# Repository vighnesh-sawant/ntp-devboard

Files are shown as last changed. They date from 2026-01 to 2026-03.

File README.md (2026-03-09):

# A devboard with a gps module and ethernet
This devboard will work as stratum 1 NTP server and has support for PTP also which I plan on supporting. Since this is my first hardware project I have picked simple(?) components  
It will take time from the gps module and serve it as a ptp/ntp server over the lan9250.

# Why
Mostly for fun but I WANT MY LAPTOP TO HAVE MORE ACCURATE TIME THAN MY FRIENDS.
I used to do this same thing with a phone but its accuracy was on the same level as ntp over the public internet  
Thats why I wanted my own STRATUM 1 Server at home, this is also a good project for learning a variety of different stuff ranging from pcb development to writing drivers to messing with ptp.

# How
Get this pcb printed, make sure to get a gps module with a PPS pin and connect the pins via breadboard / soldering   
to the gpio pins of the rp2040, then use my firmware and connect the ethernet cable to your pc.  
Make sure to change the gpio pins in the header to the ones you have connected.
Change your ntp server to point to the rp2040's ip and then done!  
You have your own stratum 1 ntp server  
More instrucions coming after I get my PCB printed!

# Schematic and stuff





# BOM TABLE

| JLCPCB BOM Tool - BOM Matching | | | | | | | | | | | | | | | | | |
| --- | --- | --- | --- | --- | --- | --- | --- | --- | --- | --- | --- | --- | --- | --- | --- | --- | --- |
| BOM name：rev4_bom-JLCPCB Assembly Order.xlsx | | | Download Time：2026-03-09 22:30:55 | | | | * Our matching results are updated in real-time, but stock and prices may change. 
If it's been over 24 hours, please re-match before placing your order. |                |                                                                                                                                                                                                             |                                                            |                                                                                                                         |                   |                                                                          |          |     |           |                 |
| PCB Assembled Qty：5                                                                                         |                   |                                  | Est. Total Price：36.7342                    |               |                    |                   |                                                                                                                                                           |                |                                                                                                                                                                                                             |                                                            |                                                                                                                         |                   |                                                                          |          |     |           |                 |
| Your BOM                                                                                                    |                   |                                  |                                             |               | Matched Parts      |                   |                                                                                                                                                           |                |                                                                                                                                                                                                             |                                                            |                                                                                                                         | Order Information |                                                                          |          |     |           |                 |
| Top Designator                                                                                              | Bottom Designator | Comment                          | Footprint                                   | JLCPCB Part # | Matches            | Part #            | Manufacturer                                                                                                                                              | Footprint      | Description                                                                                                                                                                                                 | Category                                                   | Warning                                                                                                                 | JLCPCB Part #     | Product link                                                             | Lib Type | Qty | Source    | Total Price ($) |
| C1,C10,C23,C24                                                                                              |                   | 1uF                              | 0402                                        |               | Select by System   | CL05A105KA5NQNC   | Samsung Electro-Mechanics                                                                                                                                 | 0402           | 1uF 25V X5R ±10% 0402 Multilayer Ceramic Capacitors MLCC - SMD/SMT ROHS                                                                                                                                     | Multilayer Ceramic Capacitors MLCC - SMD/SMT               |                                                                                                                         | C52923            | https://jlcpcb.com/partdetail/53938-CL05A105KA5NQNC/C52923               | Basic    | 8   | 8 JLCPCB  | 0.032           |
| C11,C12,C17,C2,C20,C21,C22,C25,C26,C27,C28,C29,C3,C30,C31,C32,C33,C34,C35,C36,C38,C39,C4,C40,C5,C6,C7,C8,C9 |                   | 0.1uF                            | 0402                                        |               | Unconfirmed        | CL05B104KO5NNNC   | Samsung Electro-Mechanics                                                                                                                                 | 0402           | 100nF 16V X7R ±10% 0402 Multilayer Ceramic Capacitors MLCC - SMD/SMT ROHS                                                                                                                                   | Multilayer Ceramic Capacitors MLCC - SMD/SMT               | 1.The comment (CL05B104KO5NNNC) of this part does not match the one (0.1uF) provided in your BOM. Please confirm;       | C1525             | https://jlcpcb.com/partdetail/1877-CL05B104KO5NNNC/C1525                 | Basic    | 58  | 58 JLCPCB | 0.0754          |
| C13,C14                                                                                                     |                   | 10uF                             | 0603                                        |               | Select by System   | CL10A106KP8NNNC   | Samsung Electro-Mechanics                                                                                                                                 | 0603           | 10V 10uF X5R ±10% 0603 Multilayer Ceramic Capacitors MLCC - SMD/SMT ROHS                                                                                                                                    | Multilayer Ceramic Capacitors MLCC - SMD/SMT               |                                                                                                                         | C19702            | https://jlcpcb.com/partdetail/20411-CL10A106KP8NNNC/C19702               | Basic    | 4   | 4 JLCPCB  | 0.026           |
| C15,C16                                                                                                     |                   | 33pF                             | 0402                                        |               | Select by System   | 0402CG330J500NT   | FH (Guangdong Fenghua Advanced Tech)                                                                                                                      | 0402           | 33pF 50V C0G ±5% 0402 Multilayer Ceramic Capacitors MLCC - SMD/SMT ROHS                                                                                                                                     | Multilayer Ceramic Capacitors MLCC - SMD/SMT               |                                                                                                                         | C1562             | https://jlcpcb.com/partdetail/1914-0402CG330J500NT/C1562                 | Basic    | 4   | 4 JLCPCB  | 0.0048          |
| C18,C19                                                                                                     |                   | 15pF                             | 0402                                        |               | Select by System   | 0402CG150J500NT   | FH (Guangdong Fenghua Advanced Tech)                                                                                                                      | 0402           | 15pF 50V C0G ±5% 0402 Multilayer Ceramic Capacitors MLCC - SMD/SMT ROHS                                                                                                                                     | Multilayer Ceramic Capacitors MLCC - SMD/SMT               |                                                                                                                         | C1548             | https://jlcpcb.com/partdetail/1900-0402CG150J500NT/C1548                 | Basic    | 4   | 4 JLCPCB  | 0.0048          |
| C37                                                                                                         |                   | 470pF                            | 0805                                        |               | Select by System   | 0805B471K500NT    | FH (Guangdong Fenghua Advanced Tech)                                                                                                                      | 0805           | 470pF 50V X7R ±10% 0805 Multilayer Ceramic Capacitors MLCC - SMD/SMT ROHS                                                                                                                                   | Multilayer Ceramic Capacitors MLCC - SMD/SMT               |                                                                                                                         | C1743             | https://jlcpcb.com/partdetail/2095-0805B471K500NT/C1743                  | Basic    | 2   | 2 JLCPCB  | 0.0104          |
| FB1,FB2,FB3,FB4                                                                                             |                   | FerriteBead                      | 0603                                        |               | Select by Customer | GZ1608D601TF      | Sunlord                                                                                                                                                   | 0603           | -55℃~+125℃ 1 200mA 450mΩ 600Ω@100MHz ±25% 0603 Ferrite Beads ROHS                                                                                                                                           | Ferrite Beads                                              |                                                                                                                         | C1002             | https://jlcpcb.com/partdetail/Sunlord-GZ1608D601TF/C1002                 | Basic    | 8   | 8 JLCPCB  | 0.1048          |
| J1                                                                                                          |                   | USB_C_Receptacle_USB2.0_14P      | USB_C_Receptacle_HRO_TYPE-C-31-M-12         |               | Select by Customer | TYPE-C-31-M-12    | Korean Hroparts Elec                                                                                                                                      | SMD            | -30℃~+80℃ 1 10,000 cycles 16P 20V 5A 7.35mm Female Surface Mount, Right Angle Type-C SMD USB Connectors ROHS                                                                                                | USB Connectors                                             |                                                                                                                         | C165948           | https://jlcpcb.com/partdetail/Korean_HropartsElec-TYPE_C_31_M12/C165948  | Extended | 2   | 2 JLCPCB  | 0.362           |
| R1,R2                                                                                                       |                   | 5.1K                             | 0402                                        |               | Unconfirmed        | 0402WGF5101TCE    | UNI-ROYAL(Uniroyal Elec)                                                                                                                                  | 0402           | -55℃~+155℃ 5.1kΩ 50V 62.5mW Thick Film Resistor ±1% ±100ppm/℃ 0402 Chip Resistor - Surface Mount ROHS                                                                                                       | Chip Resistor - Surface Mount                              | 1.The comment (0402WGF5101TCE) of this part does not match the one (5.1K) provided in your BOM. Please confirm;         | C25905            | https://jlcpcb.com/partdetail/26648-0402WGF5101TCE/C25905                | Basic    | 4   | 4 JLCPCB  | 0.0032          |
| R3,R4                                                                                                       |                   | 22                               | 0402                                        |               | Unconfirmed        | 0402WGF220JTCE    | UNI-ROYAL(Uniroyal Elec)                                                                                                                                  | 0402           | -55℃~+155℃ 22Ω 50V 62.5mW Thick Film Resistor ±1% ±100ppm/℃ 0402 Chip Resistor - Surface Mount ROHS                                                                                                         | Chip Resistor - Surface Mount                              | 1.The comment (0402WGF220JTCE) of this part does not match the one (22) provided in your BOM. Please confirm;           | C25092            | https://jlcpcb.com/partdetail/25835-0402WGF220JTCE/C25092                | Basic    | 4   | 4 JLCPCB  | 0.0032          |
| R5,R6,R8                                                                                                    |                   | 1K                               | 0402                                        |               | Unconfirmed        | 0402WGF1001TCE    | UNI-ROYAL(Uniroyal Elec)                                                                                                                                  | 0402           | -55℃~+155℃ 1kΩ 50V 62.5mW Thick Film Resistor ±1% ±100ppm/℃ 0402 Chip Resistor - Surface Mount ROHS                                                                                                         | Chip Resistor - Surface Mount                              | 1.The comment (0402WGF1001TCE) of this part does not match the one (1K) provided in your BOM. Please confirm;           | C11702            | https://jlcpcb.com/partdetail/12256-0402WGF1001TCE/C11702                | Basic    | 6   | 6 JLCPCB  | 0.0042          |
| R10,R11,R12,R13,R16,R7,R9                                                                                   |                   | 10K                              | 0402                                        |               | Unconfirmed        | 0402WGF1002TCE    | UNI-ROYAL(Uniroyal Elec)                                                                                                                                  | 0402           | -55℃~+155℃ 10kΩ 50V 62.5mW Thick Film Resistor ±1% ±100ppm/℃ 0402 Chip Resistor - Surface Mount ROHS                                                                                                        | Chip Resistor - Surface Mount                              | 1.The comment (0402WGF1002TCE) of this part does not match the one (10K) provided in your BOM. Please confirm;          | C25744            | https://jlcpcb.com/partdetail/26487-0402WGF1002TCE/C25744                | Basic    | 14  | 14 JLCPCB | 0.0112          |
| R15                                                                                                         |                   | 12K                              | 0402                                        |               | Unconfirmed        | 0402WGF1202TCE    | UNI-ROYAL(Uniroyal Elec)                                                                                                                                  | 0402           | -55℃~+155℃ 12kΩ 50V 62.5mW Thick Film Resistor ±1% ±100ppm/℃ 0402 Chip Resistor - Surface Mount ROHS                                                                                                        | Chip Resistor - Surface Mount                              | 1.The comment (0402WGF1202TCE) of this part does not match the one (12K) provided in your BOM. Please confirm;          | C25752            | https://jlcpcb.com/partdetail/26495-0402WGF1202TCE/C25752                | Basic    | 2   | 2 JLCPCB  | 0.0014          |
| SW1                                                                                                         |                   | SW_Push                          | SW_Push_SPST_NO_Alps_SKRK                   |               | Select by Customer | TS-1088-AR02016   | XUNPU                                                                                                                                                     | SMD,4x3mm      | -30℃~+80℃ 1.6N 100,000 cycles 12V 2mm 3mm 4mm 50mA Black Round Button SMD(SMT) Tab SPST Surface Mount,Vertical Without Bracket SMD,4x3mm Tactile Switches ROHS                                              | Tactile Switches                                           |                                                                                                                         | C720477           | https://jlcpcb.com/partdetail/XUNPU-TS_1088AR02016/C720477               | Basic    | 2   | 2 JLCPCB  | 0.111           |
| U1                                                                                                          |                   | RP2040                           | QFN-56-1EP_7x7mm_P0.4mm_EP3.2x3.2mm         |               | Select by Customer | RP2040            | Raspberry Pi                                                                                                                                              | LQFN-56(7x7)   | 12bit 133MHz 30 LQFN-56(7x7) Microcontrollers (MCU/MPU/SOC) ROHS                                                                                                                                            | Microcontrollers (MCU/MPU/SOC)                             |                                                                                                                         | C2040             | https://jlcpcb.com/partdetail/RaspberryPi-RP2040/C2040                   | Extended | 2   | 2 JLCPCB  | 1.9298          |
| U2                                                                                                          |                   | MCP1700x-330xxTT                 | SOT-23                                      |               | Select by Customer | MCP1700T-3302E/TT | Microchip Tech                                                                                                                                            | SOT-23         | -40℃~+125℃@(Tj) 1 1.6uA 178mV@(250mA) 250mA 3.3V 44dB@(100Hz) 6V Fixed Over Temperature Protection、Short Circuit Protection Positive SOT-23 Voltage Regulators - Linear, Low Drop Out (LDO) Regulators ROHS | Voltage Regulators - Linear, Low Drop Out (LDO) Regulators |                                                                                                                         | C39051            | https://jlcpcb.com/partdetail/MicrochipTech-MCP1700T_3302ETT/C39051      | Extended | 5   | 5 JLCPCB  | 2.193           |
| U3                                                                                                          |                   | LAN9250/ML                       | QFN64_ML_MCH                                |               | Select by System   | LAN9250/ML        | Microchip Tech                                                                                                                                            | QFN-64-EP(9x9) | QFN-64-EP(9x9) Ethernet Controllers ROHS                                                                                                                                                                    | Ethernet Controllers                                       |                                                                                                                         | C633497           | https://jlcpcb.com/partdetail/MicrochipTech-LAN9250ML/C633497            | Extended | 2   | 2 JLCPCB  | 28.7744         |
| U4                                                                                                          |                   | W25Q16JVUXIQTR                   | Winbond_USON-8-1EP_3x2mm_P0.5mm_EP0.2x1.6mm |               | Select by Customer | W25Q16JVUXIQ      | Winbond Elec                                                                                                                                              | USON-8-EP(2x3) | -40℃~+85℃ 100,000 cycles 10uA 133MHz 16Mbit 2.7V~3.6V 20 Years 3ms SPI USON-8-EP(2x3) NOR FLASH ROHS                                                                                                        | NOR FLASH                                                  | 1.The comment (W25Q16JVUXIQ) of this part does not match the one (W25Q16JVUXIQTR) provided in your BOM. Please confirm; | C2843335          | https://jlcpcb.com/partdetail/WinbondElec-W25Q16JVUXIQ/C2843335          | Extended | 2   | 2 JLCPCB  | 2.792           |
| Y1                                                                                                          |                   | 12MHz                            | Crystal_SMD_3225-4Pin_3.2x2.5mm             |               | Select by Customer | X322512MSB4SI     | YXC Crystal Oscillators                                                                                                                                   | SMD3225-4P     | -40℃~+85℃ 12MHz 20pF Crystal Oscillator ±10ppm ±20ppm SMD3225-4P Crystals ROHS                                                                                                                              | Crystals                                                   |                                                                                                                         | C9002             | https://jlcpcb.com/partdetail/YXC_CrystalOscillators-X322512MSB4SI/C9002 | Basic    | 2   | 2 JLCPCB  | 0.145           |
| Y2                                                                                                          |                   | 25MHz                            | Crystal_SMD_3225-4Pin_3.2x2.5mm             |               | Select by Customer | X322525MOB4SI     | YXC Crystal Oscillators                                                                                                                                   | SMD3225-4P     | -40℃~+85℃ 12pF 25MHz Crystal Oscillator ±10ppm ±20ppm SMD3225-4P Crystals ROHS                                                                                                                              | Crystals                                                   |                                                                                                                         | C9006             | https://jlcpcb.com/partdetail/YXC_CrystalOscillators-X322525MOB4SI/C9006 | Basic    | 2   | 2 JLCPCB  | 0.1456          |
| J2                                                                                                          |                   | Conn_01x07                       | PinHeader_1x07_P2.54mm_Vertical             |               | No matches         | No Part Selected  |                                                                                                                                                           |                |                                                                                                                                                                                                             |                                                            |                                                                                                                         |                   |                                                                          |          |     |           |                 |
| J4                                                                                                          |                   | Conn_01x04                       | PinHeader_1x04_P2.54mm_Vertical             |               | No matches         | No Part Selected  |                                                                                                                                                           |                |                                                                                                                                                                                                             |                                                            |                                                                                                                         |                   |                                                                          |          |     |           |                 |
| J5                                                                                                          |                   | Conn_01x02                       | PinHeader_1x02_P2.54mm_Vertical             |               | No matches         | No Part Selected  |                                                                                                                                                           |                |                                                                                                                                                                                                             |                                                            |                                                                                                                         |                   |                                                                          |          |     |           |                 |
| J6                                                                                                          |                   | RJ45_Hanrun_HR911105A_Horizontal | RJ45_Hanrun_HR911105A_Horizontal            |               | No matches         | No Part Selected  |                                                                                                                                                           |                |                                                                                                                                                                                                             |                                                            |                                                                                                                         |                   |                                                                          |          |     |           |                 |
| Index | LCSC#    | MPN                   | Manufacturer                  | Package               | Customer # | Description                                                           | RoHS | Quantity | MOQ | Multiple | Unit Price($) | Extended Price($) | Product Link                                      |
| ------ | -------- | --------------------- | ----------------------------- | --------------------- | ---------- | --------------------------------------------------------------------- | ---- | -------- | --- | -------- | ------------- | ----------------- | ------------------------------------------------- |
| 1      | C12074   | HR911105A             | HANRUN(Zhongshan HanRun Elec) | Through Hole          |            | Jack Modular Connector RJ45 Through Hole                              | yes  | 2        | 1   | 1        | 1.4814        | 2.96              | https://www.lcsc.com/product-detail/C12074.html   |
| 2      | C2337    | 2.54-1*40P            | BOOMELE(Boom Precision Elec)  | Through Hole,P=2.54mm |            | Pin Header 40 Position 2.54mm Pitch Single Row Through Hole -25℃~+85℃ | yes  | 5        | 5   | 5        | 0.1372        | 0.69              | https://www.lcsc.com/product-detail/C2337.html    |
| 3      | C5139763 | HS13L01WZ01           | HS                            | -                     |            | 1.3 128x64 sh1106 SPI LCD, OLED, Graphic RoHS                         | yes  | 2        | 1   | 1        | 4.6311        | 9.26              | https://www.lcsc.com/product-detail/C5139763.html |
| 4      | C9753    | DS18B20+              | MAXIM                         | TO-92                 |            | -55℃~+125℃ Single-bus 3V~5.5V TO-92 Analog and Digital Output RoHS    | yes  | 1        | 1   | 1        | 1.1630        | 1.16              | https://www.lcsc.com/product-detail/C9753.html    |
| 5      | C784382  | BWGNSCNX18-18B1Y2L120 | BAT WIRELESS                  | -                     |            | RF ANTENNA Ceramic                                                    | yes  | 1        | 1   | 1        | 1.6729        | 1.67              | https://www.lcsc.com/product-detail/C784382.html  |

A Gps module with a PPS pin https://roboticsdna.in/product/gps-neo-6m-satellite-positioning-module-development-board-for-arduino-stm32-51/  
Jumper wire https://roboticsdna.in/product/65pcs-flexible-breadboard-jumper-wires/  
Bread Board https://roboticsdna.in/product/syb-170-black-mini-solderless-breadboard/

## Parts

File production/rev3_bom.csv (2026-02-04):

Designator | Footprint | Quantity | Value | LCSC Part #
C1, C10, C23, C24 | 0402 | 4 | 1uF
C11, C12, C17, C2, C20, C21, C22, C25, C26, C27, C28, C29, C3, C30, C31, C32, C33, C34, C35, C36, C38, C39, C4, C40, C5, C6, C7, C8, C9 | 0402 | 29 | 0.1uF
C13, C14 | 0603 | 2 | 10uF
C15, C16 | 0402 | 2 | 33pF
C18, C19 | 0402 | 2 | 15pF
C37 | 0805 | 1 | 470pF
FB1, FB2, FB3, FB4 | 0603 | 4 | FerriteBead
J1 | USB_C_Receptacle_HRO_TYPE-C-31-M-12 | 1 | USB_C_Receptacle_USB2.0_14P
J2 | PinHeader_1x07_P2.54mm_Vertical | 1 | Conn_01x07
J3 | PinHeader_1x20_P2.54mm_Vertical | 1 | Conn_01x20
J4 | PinHeader_1x04_P2.54mm_Vertical | 1 | Conn_01x04
J5 | PinHeader_1x02_P2.54mm_Vertical | 1 | Conn_01x02
J6 | RJ45_Hanrun_HR911105A_Horizontal | 1 | RJ45_Hanrun_HR911105A_Horizontal
R1, R2 | 0402 | 2 | 5.1K
R10, R11, R12, R13, R16, R7, R9 | 0402 | 7 | 10K
R15 | 0402 | 1 | 12K
R3, R4 | 0402 | 2 | 22
R5, R6, R8 | 0402 | 3 | 1K
SW1 | SW_Push_SPST_NO_Alps_SKRK | 1 | SW_Push
U1 | QFN-56-1EP_7x7mm_P0.4mm_EP3.2x3.2mm | 1 | RP2040
U2 | SOT-23 | 1 | MCP1700x-330xxTT
U3 | QFN64_ML_MCH | 1 | LAN9250/ML
U4 | Winbond_USON-8-1EP_3x2mm_P0.5mm_EP0.2x1.6mm | 1 | W25Q16JVUXIQ TR
Y1 | Crystal_SMD_3225-4Pin_3.2x2.5mm | 1 | 12 MHz
Y2 | Crystal_SMD_3225-4Pin_3.2x2.5mm | 1 | 25 MHz

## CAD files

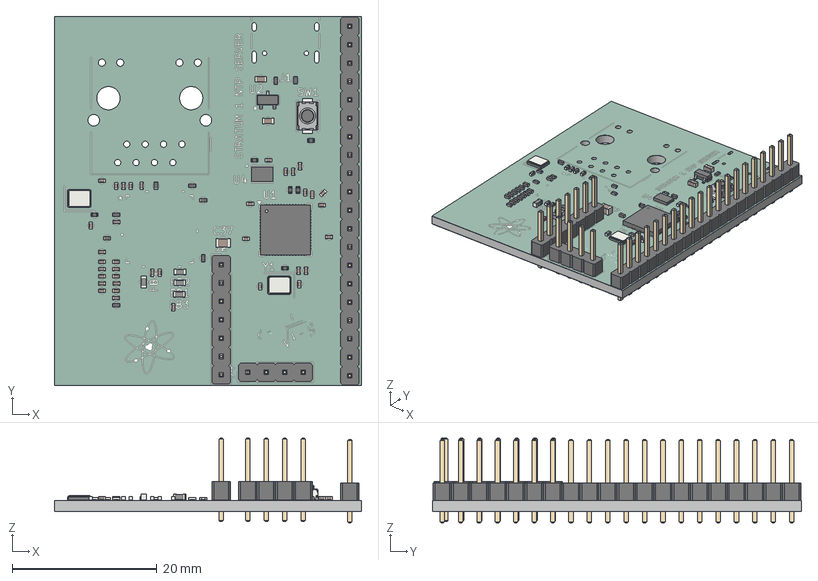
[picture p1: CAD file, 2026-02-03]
ntp-devboard.step
42.4 x 51.0 x 11.7 mm
C_0402_1005Metric x 37
R_0402_1005Metric x 15
C_0603_1608Metric x 2
Crystal_SMD_3225-4Pin_3.2x2.5mm x 2
L_0603_1608Metric x 4
PinHeader_1x04_P2.54mm_Vertical
C_0805_2012Metric
SW_Push_SPST_NO_Alps_SKRK
PinHeader_1x07_P2.54mm_Vertical
QFN-56-1EP_7x7mm_P0.4mm_EP3.2x3.2mm
SOT-23
Winbond_USON-8-1EP_3x2mm_P0.5mm_EP0.2x1.6mm
PinHeader_1x20_P2.54mm_Vertical
ntp-devboard_silkscreen x 2
ntp-devboard_soldermask x 2
ntp-devboard_PCB

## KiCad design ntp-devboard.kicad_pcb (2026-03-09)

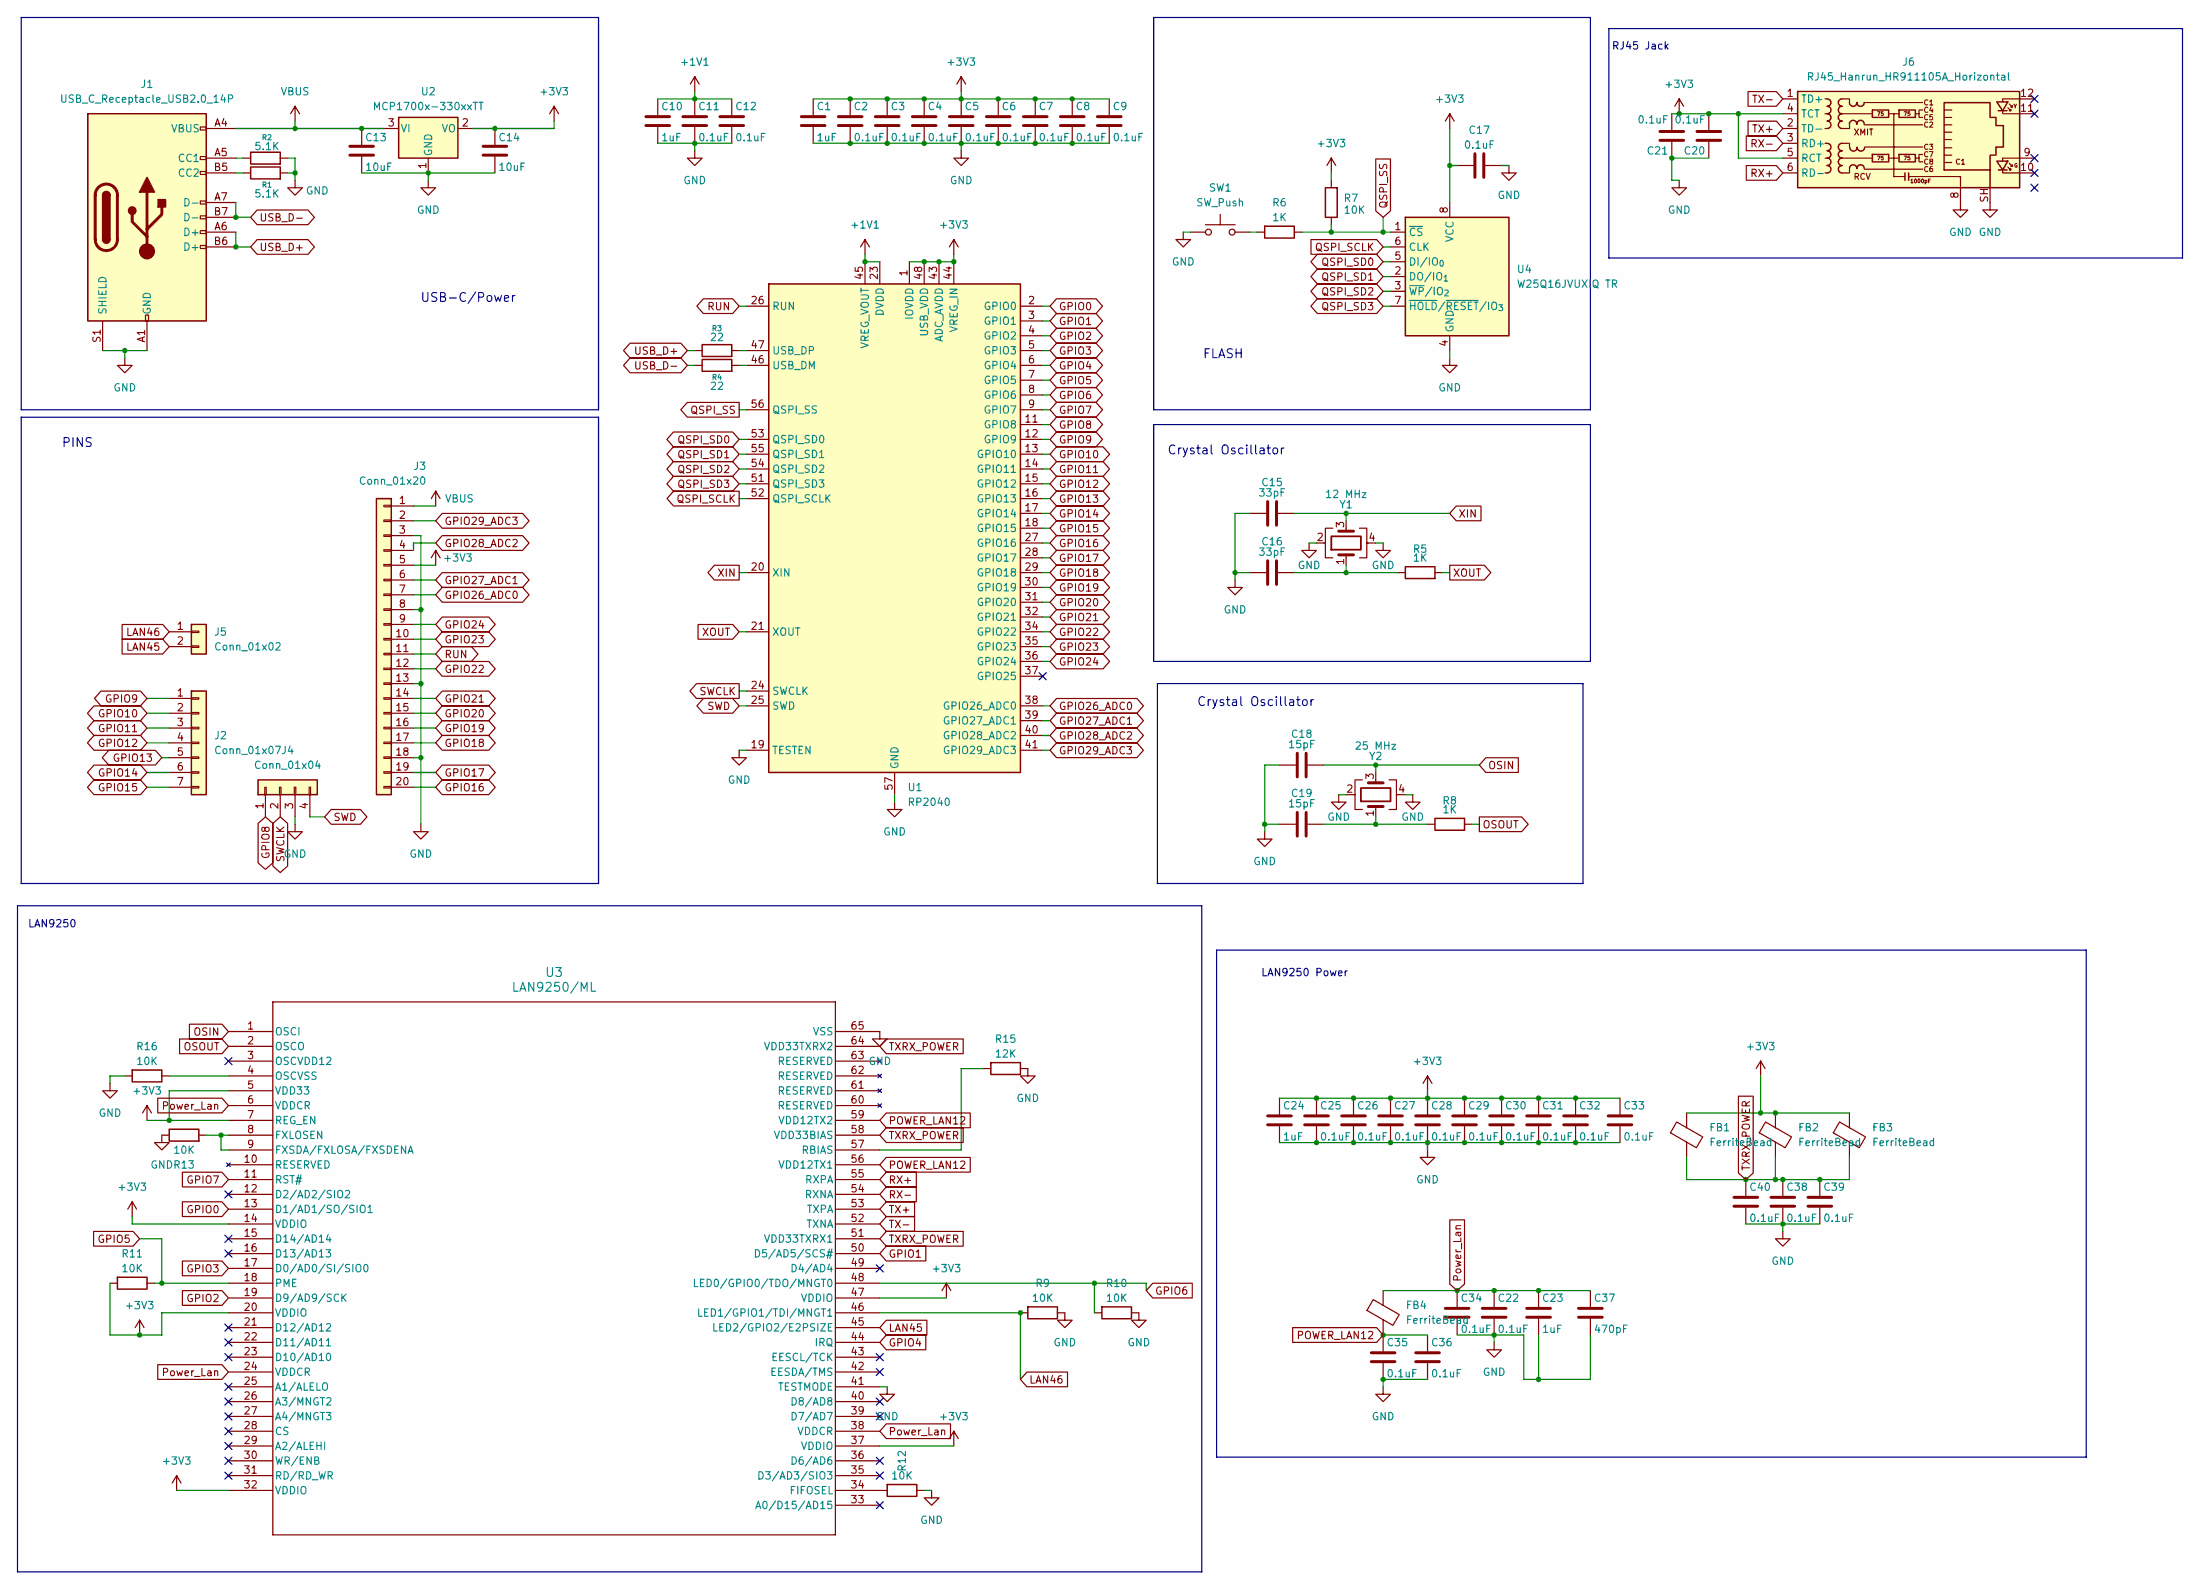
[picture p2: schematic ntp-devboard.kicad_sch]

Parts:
C1, C10, C23, C24: 1uF; C_0402_1005Metric
C2, C3, C4, C5, C6, C7, C8, C9, C11, C12, C17, C20, C21, C22, C25, C26, C27, C28, C29, C30, C31, C32, C33, C34, C35, C36, C38, C39, C40: 0.1uF; C_0402_1005Metric
C13, C14: 10uF; C_0603_1608Metric
C15, C16: 33pF; C_0402_1005Metric
C18, C19: 15pF; C_0402_1005Metric
C37: 470pF; C_0805_2012Metric
FB1, FB2, FB3, FB4: FerriteBead; L_0603_1608Metric
J1: USB_C_Receptacle_USB2.0_14P; USB_C_Receptacle_HRO_TYPE-C-31-M-12
J2: Conn_01x07; PinHeader_1x07_P2.54mm_Vertical
J3: Conn_01x20; PinHeader_1x20_P2.54mm_Vertical
J4: Conn_01x04; PinHeader_1x04_P2.54mm_Vertical
J5: Conn_01x02; PinHeader_1x02_P2.54mm_Vertical
J6: RJ45_Hanrun_HR911105A_Horizontal
R1, R2: 5.1K; R_0402_1005Metric
R3, R4: 22; R_0402_1005Metric
R5, R6, R8: 1K; R_0402_1005Metric
R7, R9, R10, R11, R12, R13, R16: 10K; R_0402_1005Metric
R15: 12K; R_0402_1005Metric
SW1: SW_Push; SW_Push_SPST_NO_Alps_SKRK
U1: RP2040; QFN-56-1EP_7x7mm_P0.4mm_EP3.2x3.2mm
U2: MCP1700x-330xxTT; SOT-23
U3: LAN9250/ML; QFN64_ML_MCH
U4: W25Q16JVUXIQ TR; Winbond_USON-8-1EP_3x2mm_P0.5mm_EP0.2x1.6mm
Y1: 12 MHz; Crystal_SMD_3225-4Pin_3.2x2.5mm
Y2: 25 MHz; Crystal_SMD_3225-4Pin_3.2x2.5mm

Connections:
+1V1: C10.1, C11.1, C12.1, U1.23 (DVDD), U1.45 (VREG_VOUT), U1.50 (DVDD)
+3V3: C1.1, C2.1, C3.1, C4.1, C5.1, C6.1, C7.1, C8.1, C9.1, C14.1, C17.1, C20.2, C21.2, C24.1, C25.1, C26.1, C27.1, C28.1, C29.1, C30.1, C31.1, C32.1, C33.1, FB1.1, FB2.1, FB3.1, J3.5, J6.4 (TCT), J6.5 (RCT), R7.2, R11.2, U1.1 (IOVDD), U1.10 (IOVDD), U1.22 (IOVDD), U1.33 (IOVDD), U1.42 (IOVDD), U1.43 (ADC_AVDD), U1.44 (VREG_IN), U1.48 (USB_VDD), U1.49 (IOVDD), U2.2 (VO), U3.5 (VDD33), U3.7 (REG_EN), U3.14 (VDDIO), U3.20 (VDDIO), U3.32 (VDDIO), U3.37 (VDDIO), U3.47 (VDDIO), U4.8 (VCC)
GND: C1.2, C2.2, C3.2, C4.2, C5.2, C6.2, C7.2, C8.2, C9.2, C10.2, C11.2, C12.2, C13.2, C14.2, C15.1, C16.1, C17.2, C18.1, C19.1, C20.1, C21.1, C22.2, C23.2, C24.2, C25.2, C26.2, C27.2, C28.2, C29.2, C30.2, C31.2, C32.2, C33.2, C34.2, C35.2, C36.2, C37.2, C38.2, C39.2, C40.2, J1.A1 (GND), J1.A12 (GND), J1.B1 (GND), J1.B12 (GND), J1.S1 (SHIELD), J3.3, J3.8, J3.13, J3.18, J4.3, J6.8, J6.SH, R1.2, R2.2, R9.1, R10.1, R12.1, R13.1, R15.1, R16.2, SW1.1, U1.19 (TESTEN), U1.57 (GND), U2.1 (GND), U3.41 (TESTMODE), U3.65 (VSS), U4.4 (GND), Y1.2, Y1.4, Y2.2, Y2.4
GPIO0: U1.2 (GPIO0), U3.13 (D1/AD1/SO/SIO1)
GPIO1: U1.3 (GPIO1), U3.50 (D5/AD5/SCS#)
GPIO2: U1.4 (GPIO2), U3.19 (D9/AD9/SCK)
GPIO3: U1.5 (GPIO3), U3.17 (D0/AD0/SI/SIO0)
GPIO4: U1.6 (GPIO4), U3.44 (IRQ)
GPIO5: R11.1, U1.7 (GPIO5), U3.18 (PME)
GPIO6: R10.2, U1.8 (GPIO6), U3.48 (LED0/GPIO0/TDO/MNGT0)
GPIO7: U1.9 (GPIO7), U3.11 (RST#)
GPIO8: J4.1, U1.11 (GPIO8)
GPIO9: J2.1, U1.12 (GPIO9)
GPIO10: J2.2, U1.13 (GPIO10)
GPIO11: J2.3, U1.14 (GPIO11)
GPIO12: J2.4, U1.15 (GPIO12)
GPIO13: J2.5, U1.16 (GPIO13)
GPIO14: J2.6, U1.17 (GPIO14)
GPIO15: J2.7, U1.18 (GPIO15)
GPIO16: J3.20, U1.27 (GPIO16)
GPIO17: J3.19, U1.28 (GPIO17)
GPIO18: J3.17, U1.29 (GPIO18)
GPIO19: J3.16, U1.30 (GPIO19)
GPIO20: J3.15, U1.31 (GPIO20)
GPIO21: J3.14, U1.32 (GPIO21)
GPIO22: J3.12, U1.34 (GPIO22)
GPIO23: J3.10, U1.35 (GPIO23)
GPIO24: J3.9, U1.36 (GPIO24)
GPIO26_ADC0: J3.7, U1.38 (GPIO26_ADC0)
GPIO27_ADC1: J3.6, U1.39 (GPIO27_ADC1)
GPIO28_ADC2: J3.4, U1.40 (GPIO28_ADC2)
GPIO29_ADC3: J3.2, U1.41 (GPIO29_ADC3)
LAN45: J5.2, U3.45 (LED2/GPIO2/E2PSIZE)
LAN46: J5.1, R9.2, U3.46 (LED1/GPIO1/TDI/MNGT1)
unnamed: C16.2, R5.1, Y1.1
unnamed: C19.2, R8.1, Y2.1
unnamed: J1.A5 (CC1), R2.1
unnamed: J1.B5 (CC2), R1.1
unnamed: R6.2, SW1.2
unnamed: R4.2, U1.46 (USB_DM)
unnamed: R3.2, U1.47 (USB_DP)
unnamed: R12.2, U3.34 (FIFOSEL)
unnamed: R13.2, U3.8 (FXLOSEN), U3.9 (FXSDA/FXLOSA/FXSDENA)
unnamed: R16.1, U3.4 (OSCVSS)
unnamed: R15.2, U3.57 (RBIAS)
OSIN: C18.2, U3.1 (OSCI), Y2.3
OSOUT: R8.2, U3.2 (OSCO)
POWER_LAN12: C35.1, C36.1, FB4.2, U3.56 (VDD12TX1), U3.59 (VDD12TX2)
Power_Lan: C22.1, C23.1, C34.1, C37.1, FB4.1, U3.6 (VDDCR), U3.24 (VDDCR), U3.38 (VDDCR)
QSPI_SCLK: U1.52 (QSPI_SCLK), U4.6 (CLK)
QSPI_SD0: U1.53 (QSPI_SD0), U4.5 (DI/IO_{0})
QSPI_SD1: U1.55 (QSPI_SD1), U4.2 (DO/IO_{1})
QSPI_SD2: U1.54 (QSPI_SD2), U4.3 (~WP/IO_{2})
QSPI_SD3: U1.51 (QSPI_SD3), U4.7 (~HOLD/~RESET/IO_{3})
QSPI_SS: R6.1, R7.1, U1.56 (QSPI_SS), U4.1 (~CS)
RUN: J3.11, U1.26 (RUN)
RX+: J6.6 (RD-), U3.55 (RXPA)
RX-: J6.3 (RD+), U3.54 (RXNA)
SWCLK: J4.2, U1.24 (SWCLK)
SWD: J4.4, U1.25 (SWD)
TX+: J6.2 (TD-), U3.53 (TXPA)
TX-: J6.1 (TD+), U3.52 (TXNA)
TXRX_POWER: C38.1, C39.1, C40.1, FB1.2, FB2.2, FB3.2, U3.51 (VDD33TXRX1), U3.58 (VDD33BIAS), U3.64 (VDD33TXRX2)
USB_D+: J1.A6 (D+), J1.B6 (D+), R3.1
USB_D-: J1.A7 (D-), J1.B7 (D-), R4.1
VBUS: C13.1, J1.A4 (VBUS), J1.A9 (VBUS), J1.B4 (VBUS), J1.B9 (VBUS), J3.1, U2.3 (VI)
XIN: C15.2, U1.20 (XIN), Y1.3
XOUT: R5.2, U1.21 (XOUT)

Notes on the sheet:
FLASH
PINS
LAN9250 Power
RJ45 Jack
LAN9250
Crystal Oscillator
USB-C/Power

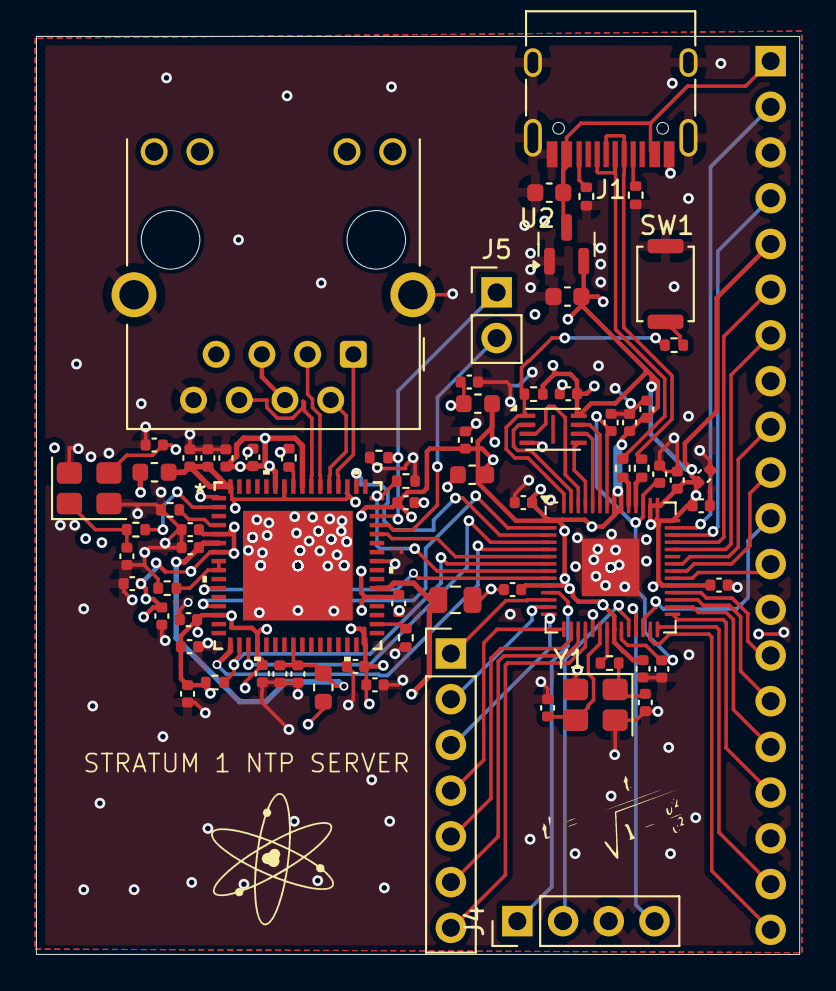
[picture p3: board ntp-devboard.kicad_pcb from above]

Board: 4 copper layers, 42.4 x 51.0 mm, 72 parts (1 on the bottom side), 68 nets.

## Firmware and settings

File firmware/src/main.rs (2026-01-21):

#![no_std]
#![no_main]

use embassy_executor::Spawner;
use embassy_rp::gpio::{Level, Output};
use embassy_rp::spi::{Config, Spi};
use embassy_time::{Duration, Timer};
use {defmt_rtt as _, panic_probe as _};

const CMD_READ: u8 = 0x03;
const ID_REV_REG: u16 = 0x50; // Offset for Chip ID and Revision

#[embassy_executor::main]
async fn main(_spawner: Spawner) {
    let p = embassy_rp::init(Default::default());

    let mut config = Config::default();
    config.frequency = 80_000_000;

    let mut spi = Spi::new(
        p.SPI0, p.PIN_2, // SCK
        p.PIN_3, // MOSI
        p.PIN_0, // MISO
        p.DMA_CH0, p.DMA_CH1, config,
    );
    //chipselect
    let mut cs = Output::new(p.PIN_1, Level::High);
    //reset
    let mut rst = Output::new(p.PIN_9, Level::High);

    defmt::info!("Starting");

    //start reset
    rst.set_low();
    Timer::after(Duration::from_millis(50)).await;
    rst.set_high();
    Timer::after(Duration::from_millis(100)).await;

    loop {
        let mut tx_buf = [0u8; 7];
        let mut rx_buf = [0u8; 7];

        tx_buf[0] = CMD_READ;
        //split bytes
        tx_buf[1] = (ID_REV_REG >> 8) as u8;
        tx_buf[2] = (ID_REV_REG & 0xFF) as u8;

        //start transc
        cs.set_low();
        let transfer_result = spi.transfer(&mut rx_buf, &tx_buf).await;
        cs.set_high();

        match transfer_result {
            Ok(_) => {
                //last 4 bytes only usefull
                let id_word = u32::from_le_bytes([rx_buf[3], rx_buf[4], rx_buf[5], rx_buf[6]]);

                defmt::info!("Read ID: {:#010x}", id_word);
            }
            Err(_) => defmt::error!("SPI Error"),
        }

        Timer::after(Duration::from_secs(1)).await;
    }
}

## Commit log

2026-01-21 Add production files
    [ntp-devboard-B_Cu.gbr, ntp-devboard-B_Mask.gbr, ntp-devboard-B_Paste.gbr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]
2026-01-21 bom optimisation
    [ntp-devboard-B_Cu.gbr, ntp-devboard-B_Mask.gbr, ntp-devboard-B_Paste.gbr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]
2026-01-25 add bom
    [bom.xls]
2026-02-03 add 3d model
    [ntp-devboard.step]
2026-02-03 uhm, _minor_ mistake
    [ntp-devboard.kicad_pcb, ntp-devboard.kicad_sch]
2026-02-04 cooked ah decoupling caps
    [ntp-devboard.kicad_pcb, ntp-devboard.kicad_sch]
2026-02-04 powertraces go brr
    [ntp-devboard.kicad_pcb]
2026-02-04 add prod files
    [rev1_bom.csv, rev1_designators.csv, rev1_positions.csv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]
2026-02-12 add lcsc.csv
    [lcsc.csv]
2026-02-18 remove old prod files
    [ntp-devboard-B_Cu.gbr, ntp-devboard-B_Mask.gbr, ntp-devboard-B_Paste.gbr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]
2026-02-18 change xls to csv
    [bom.csv, bom.xls]
2026-02-24 Improved schematic readbility
    [ntp-devboard.kicad_sch]
2026-03-09 update sch and pcb
    [ntp-devboard.kicad_pcb, ntp-devboard.kicad_sch, rev4_bom.csv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]
2026-03-09 update bom
    [bom.csv]
